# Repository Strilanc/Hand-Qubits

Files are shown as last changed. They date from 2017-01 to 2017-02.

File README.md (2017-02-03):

# Handheld Qubits

*Work in progress*

This project contains code and instructions for making simulated toy qubits that you can hold.

The basic concept is to have a bunch of balls with Arduinos and other electronics inside.
The Arduinos record motion data and report it over bluetooth to a hub computer doing the quantum simulation.
Simple ball movements (turning, knocking, and pressing together) are thereby translated into quantum operations (single-qubit rotations, measurement, controlled rotations).

The main things left to do are:

- Better debugging and testing of the Arduino code. Something is causing the contact detection to go flaky when the Arduinos are reset.
- Correcting gyrometer drift with accelerometer data.
- Correctly turning the motion into quantum rotations.
- Make a demo video demonstrating quantum teleportation.

### Demo

[[[work in progress]]]

### How To Use

- Each ball is a qubit.
- A nearby computer acts as a hub handling the quantum simulation and talking to the balls over bluetooth.
- When you **turn** a ball, its qubit is correspondingly *rotated* around the [Bloch sphere](https://en.wikipedia.org/wiki/Bloch_sphere).
- When you **knock** a ball against a surface, its qubit is *measured*. The measurement axis is always vertical, and the result is indicated by a buzzer going "Beep beep beep!" for DOWN or "Riiiiiiiing!" for UP.
- When you **press** two balls **together**, rotations become *controlled*. Turning one ball will only affect the parts of the state space where the other ball's qubit is UP.

### Making Your Own

0. **Clone the repository.**

    `git clone https://github.com/Strilanc/Hand-Qubits.git`

0. **Get the necessary parts.**

    - [ ] Arduino [Uno](https://www.arduino.cc/en/Main/ArduinoBoardUno) or [Nano](https://www.arduino.cc/en/Main/arduinoBoardNano) or similar
    - [ ] [MPU-6050](http://playground.arduino.cc/Main/MPU-6050) Accelerometer/Gyrometer ([datasheet](https://www.invensense.com/wp-content/uploads/2015/02/MPU-6000-Datasheet1.pdf))
    - [ ] [HC-05](https://www.amazon.com/CHENBO-Wireless-Bluetooth-Transceiver-Arduino/dp/B00Y0D112O) Bluetooth Module ([datasheet](https://www.olimex.com/Products/Components/RF/BLUETOOTH-SERIAL-HC-06/resources/hc06.pdf))
    - [ ] [Buzzer](https://www.amazon.com/gp/product/B00B0Q4KKO/)
    - [ ] [Switch](https://www.amazon.com/gp/product/B00ZWWZ5BA)
    - [ ] [~15cm Diameter Polystyrene Ball](https://www.amazon.com/Crafts-Brand-Smooth-Polystyrene-Styrofoam/dp/B00ETI28MC/)
    - [ ] [Conductive Paint](https://www.amazon.com/Bare-Conductive-Electric-Paint-10ml/dp/B01IO2JSCG)
    - [ ] Breadboard / Various Wires / 9V Battery / Appropriate USB Cable / Soldering Stuff / Etc

0. **Configure parts.**

    - Open `Hand-Qubits/qubit-microcontroller/qubit-microcontroller.ino` with the [Arduino IDE](https://www.arduino.cc/en/main/software)
	- Upload to the Arduino
    - Also [Configure the HC-05 Bluetooth Modules](https://arduino-info.wikispaces.com/BlueTooth-HC05-HC06-Modules-How-To).
    - Change the addresses and pins in `Hand-Qubits/hub/src/config/KnownBoards.cs` to match.
    - Pair your computer with the Bluetooth modules.

0. **Run the server.**

    - Open `Hand-Qubits/hub/HandQubitServer.sln` with [Visual Studio](https://www.visualstudio.com/vs/community/).
    - Run the project on a computer with bluetooth enabled.
    - Once you've assembled things, the powered Arduinos can connect and start feeding in data.

0. **Assemble electronics.**

    Connect `vcc` and `ground` pins appropriately.
    The MPU-6050's `SDA` and `SCL` pins go to `A5` and `A6` respectively.
    The HC-06's `RX` and `TX` pins go to `D4` and `D3` respectively.
    The buzzer goes from `A3` to `ground`.
    `A0` will go to the conductive paint or copper tape wrapping around the ball.
    Also, connect the battery and switch.

    A diagram of the pin connections:

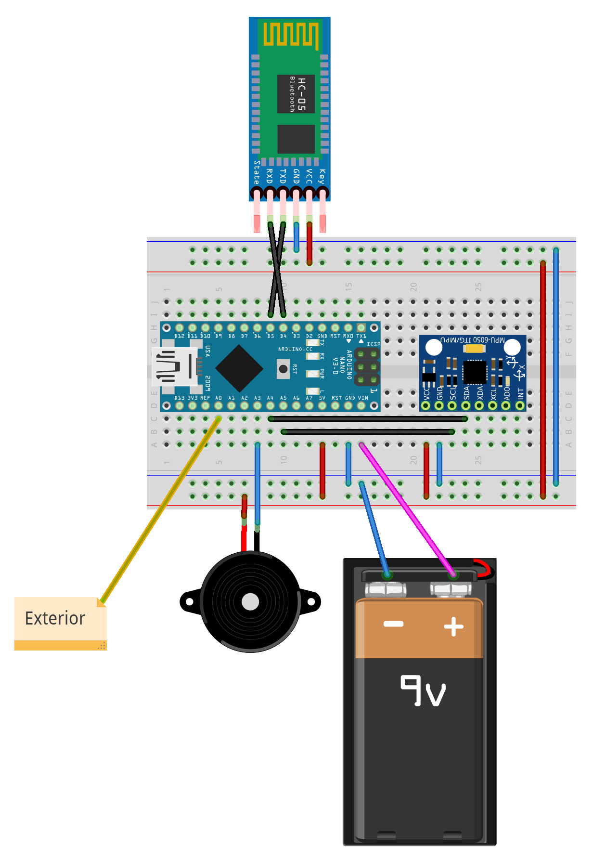
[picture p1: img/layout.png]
layout
    
	
	Once the electronics are ready, test that the powered Arduino connects and feeds motion data to the server.

0. **Assemble balls.**

    First, paint over the polystyrene ball with an acrlyic paint.
    This stops the polystyrene from shedding constantly when touched.
    After the acrylic has dried, add conductive paint traced in tangled lines all over the surface.
    Once the conductive paint has dried, cut the ball in half.
    
    Make a hole for the electronics to sit in by carving into the insides of each half-ball using a butter knife or scissors.
    Try to make the fit snug, and positioned so that the switch just barely pokes out the side.
    Once the hole is carved, paint it and the rest of the insides with acrylic so they don't shed.
    
    After placing the electronics inside, and somehow connecting A0 to the conductive paint traces, close up the halves and use an office stapler to staple them together.
    You can position the staples so they act as a conductive path from conductive paint on the top half to conductive paint on the the bottom half.

    Here are some pictures of balls in progress:

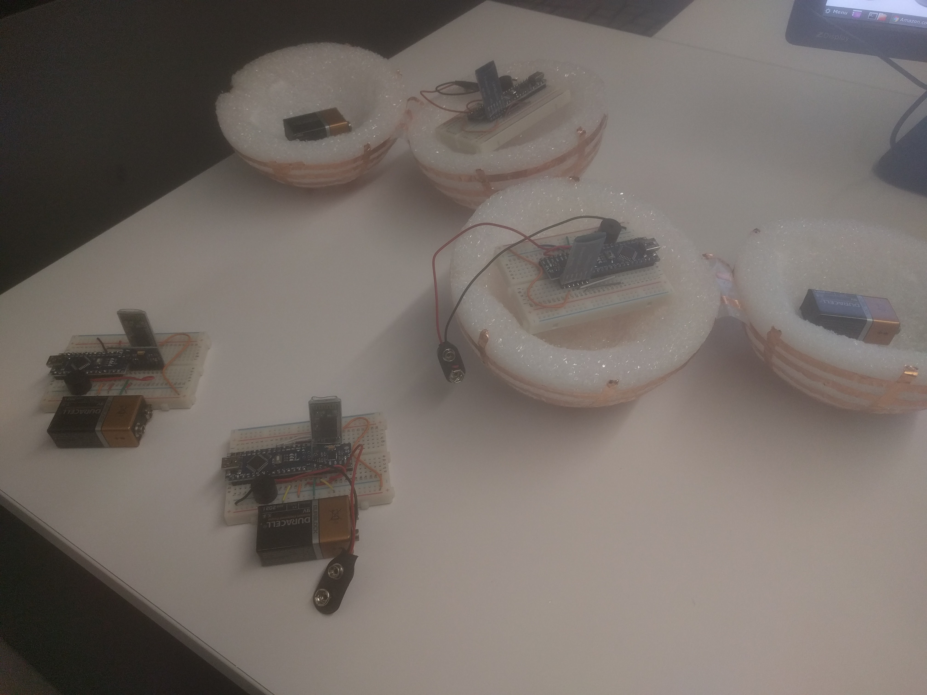
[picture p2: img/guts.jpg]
guts
    

    Staples can be pulled out easily, if you need to make changes.
    If you want a more permanent connection, such as a hinge between the backs of the two halves, I recommend sewing them together with needle and thread.
	
0. **Play with your qubits!**

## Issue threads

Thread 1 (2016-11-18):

Improve rotation-to-operation flow

Strilanc, 2016-11-18:
Feels really clunky. Easy to miss operations when not watching the screen. Hard to undo an operation sequence. Hard to hit Hadamard without hitting something in between. No correction of yaw drift.

Ideas:

- Only do "what's that operation?" inference when parked.
- Only do non-Pauli operations when parked.
- Don't ever infer an operation until an interaction with another qubit.
- Drift yaw towards rounded operation when parked.
- Beep?
- Handle axes separately.

Strilanc, 2017-01-26:
I've decided to instead just not try to round the rotations into operations.

Closed 2017-01-26.

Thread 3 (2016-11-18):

Figure out mechanism for making qubits interact

Strilanc, 2016-11-18:
Ideally, it would be as simple as just touching them together.

- What axis is being conditioned on? Gravity axis? Touch point axis?
- How to determine touching? Voltage changes through conductive skin? But then how does wireless data escape?
- What happens when both qubits are being rotated at the same time? General user confusion at the not-a-proper-gate result? Perhaps do everything in full precision then drop down to known gates if nearby at the end of the interaction?

Strilanc, 2016-12-17:
Bought copper tape. Might work to just wrap the balls with it and detect contact.

Strilanc, 2017-01-26:
This seems to be the way things are going.

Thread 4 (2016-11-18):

Make bumps trigger measurement

Strilanc, 2016-11-18:
- How should the result be communicated back? Beeping? Vibration?
- Might need a history of sensor readings, since the shake is likely to jump the gyrometer. We want the state before the shock.

Strilanc, 2016-12-17:
Squared sum of accelerometer over a small window w/ a threshold seems to work okay.

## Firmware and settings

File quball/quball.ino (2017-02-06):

#include "src/contact.h"
#include "src/motion.h"
#include "src/sound.h"

#define LED_PIN 13

#define BLUETOOTH_RXD_PIN 3
#define BLUETOOTH_TXD_PIN 4
SoftwareSerial bluetoothSerial(BLUETOOTH_RXD_PIN, BLUETOOTH_TXD_PIN);

void setup() {
  Serial.begin(9600);
  bluetoothSerial.begin(115200);
  pinMode(LED_PIN, OUTPUT);

  contact_setup();
  motion_setup();
  sound_setup();
}

void loop() {
  contact_loop();
  sound_loop();

  read_any_commands_from_serial();

  bool is_in_contact = contact_get_current_other_message() != 0xFF;
  set_ticking(is_in_contact);
  digitalWrite(LED_PIN, is_in_contact);

  motion_loop();
}

void read_any_commands_from_serial() {
  uint8_t id;
  while (bluetoothSerial.available() > 0) {
    switch (bluetoothSerial.read()) {
      case 'm':
        // Set id.
        while (bluetoothSerial.available() < 1) {
        }
        id = bluetoothSerial.read();
        contact_set_byte_to_send(id);
        break;
        
      case 'r':
        // Ring.
        queue_tone(40, 10, 8, true);
        break;

      case 'b':
        // Beep beep!
        queue_tone(80, 120, 3, true);
        break;
    }
  }
}

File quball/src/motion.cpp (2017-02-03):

#include <Arduino.h>
#include <math.h>
#include <Wire.h>

#include "motion.h"
#include "contact.h"
#include "quaternion.h"

struct vec3 {
    float x;
    float y;
    float z;
};

#define mpuAddress 0b1101000
#define ACCEL_SCALE_FACTOR ((float)(1.0 / 16.0 / 256.0 / 128.0))
#define GYRO_TIME_SCALE_FACTOR ((float)(3.14159265358979323846f / 180 / 1000 / 256 / 128))

static uint64_t last_gyro_read_time;
static vec3 bias;
static float gyration;
static int calibration_readings;
static Quaternion pose;
static vec3 accel;
static int accumulate_count;
static float bumpiness;
static int request_state;
static int request_state_buf[6];

void setupMPU();

void motion_reset() {
    request_state = 0;
    last_gyro_read_time = 0;
    bias = { 0, 0, 0 };
    gyration = 0;
    calibration_readings = 0;
    pose = { 1, 0, 0, 0 };
    accel = { 0, 0, 0 };
    accumulate_count = 0;
    bumpiness = 0;
}

void motion_setup() {
    motion_reset();

    Wire.begin();
    Wire.setClock(400000L); // max supported by MPU-6050
    setupMPU();
}

void mpuSendPair(int a, int b) {
    Wire.beginTransmission(mpuAddress);
    Wire.write(a);
    Wire.write(b);
    Wire.endTransmission();
}

void setupMPU() {
    //Accessing the register 6B - Power Management (Sec. 4.28)
    //Setting SLEEP register to 0. (Required; see Note on p. 9)
    mpuSendPair(0x6B, 0);

    // Set gyro range.
    int REG_GYRO_RANGE = 0x1B;
    int FLAG_GYRO_RANGE_DEG_PER_SEC_250 = 0x00;
    int FLAG_GYRO_RANGE_DEG_PER_SEC_500 = 0x08;
    int FLAG_GYRO_RANGE_DEG_PER_SEC_1000 = 0x10;
    int FLAG_GYRO_RANGE_DEG_PER_SEC_2000 = 0x18;
    mpuSendPair(REG_GYRO_RANGE, FLAG_GYRO_RANGE_DEG_PER_SEC_1000);

    //Accessing the register 1C - Acccelerometer Configuration (Sec. 4.5) 
    //Setting the accel to +/- 16g
    mpuSendPair(0x1C, 0x18);
}

bool mpuTryMotionRequest(vec3& accel, vec3& gyro) {
    switch (request_state) {
    case 0:
        // Request accelerometer data.
        Wire.beginTransmission(mpuAddress);
        Wire.write(0x3B);
        Wire.endTransmission();
        Wire.requestFrom(mpuAddress, 6);
        request_state = 1;
    case 1:
        if (Wire.available() < 6) {
            return false;
        }
        for (int i = 0; i < 3; i++) {
            request_state_buf[i] = Wire.read() << 8;
            request_state_buf[i] |= Wire.read();
        }
        request_state = 2;
    case 2:
        // Request gyrometer data.
        Wire.beginTransmission(mpuAddress);
        Wire.write(0x43);
        Wire.endTransmission();
        Wire.requestFrom(mpuAddress, 6);
        request_state = 3;
    default:
        if (Wire.available() < 6) {
            return false;
        }
        for (int i = 0; i < 3; i++) {
            request_state_buf[i+3] = Wire.read() << 8;
            request_state_buf[i+3] |= Wire.read();
        }

        // Dump into values.
        accel.x = (float)request_state_buf[0] * ACCEL_SCALE_FACTOR;
        accel.y = (float)request_state_buf[1] * ACCEL_SCALE_FACTOR;
        accel.z = (float)request_state_buf[2] * ACCEL_SCALE_FACTOR;
        gyro.x = (float)request_state_buf[3];
        gyro.y = (float)request_state_buf[4];
        gyro.z = (float)request_state_buf[5];
        request_state = 0;
        return true;
    }
}

void serialWriteInt(int s) {
    bluetoothSerial.write((byte)(s & 0xFF));
    bluetoothSerial.write((byte)((s >> 8) & 0xFF));
}
void serialWriteFloat(float f) {
    bluetoothSerial.write((byte*)(void*)&f, 4);
}
void serialWriteVec3(vec3 v) {
    serialWriteFloat(v.x);
    serialWriteFloat(v.y);
    serialWriteFloat(v.z);
}
void serialWriteQuaternion(Quaternion q) {
    serialWriteFloat(q.w);
    serialWriteFloat(q.x);
    serialWriteFloat(q.y);
    serialWriteFloat(q.z);
}

Quaternion angularVelocitiesToQuaternion(vec3 v) {
    // If still early, build up average to calibrate zero bias.
    float g = v.x*v.x + v.y*v.y + v.z*v.z;
    gyration = gyration * 0.9f + g * 0.1f;
    if (gyration < 100000.0 && calibration_readings < 10000) {
        calibration_readings++;
        float a = 0.999f;
        float b = 1 - a;
        bias.x *= a;
        bias.y *= a;
        bias.z *= a;
        bias.x += b * v.x;
        bias.y += b * v.y;
        bias.z += b * v.z;
    }

    // Cancel out estimated bias.
    v.x -= bias.x;
    v.y -= bias.y;
    v.z -= bias.z;

    // Duration to integrate over.
    uint64_t t = micros();
    int dt = (int)(t - last_gyro_read_time);
    last_gyro_read_time = t;

    // Estimated rotation over sample duration.
    float dw = dt * GYRO_TIME_SCALE_FACTOR;
    return Quaternion::from_angular_impulse(v.x * dw, v.y * dw, v.z * dw);
}

void send_accumulated_motion_and_reset() {
    bluetoothSerial.write(0xA9);
    bluetoothSerial.write(0x42);
    bluetoothSerial.write(contact_get_byte_to_send());
    bluetoothSerial.write(contact_get_current_other_message());
    serialWriteQuaternion(pose);
    serialWriteVec3(accel);
    serialWriteFloat(bumpiness);

    bumpiness = 0;
    accel.x = 0;
    accel.y = 0;
    accel.z = 0;
    pose = Quaternion{ 1, 0, 0, 0 };
}

void motion_loop() {
    vec3 acc, gyr;
    if (!mpuTryMotionRequest(acc, gyr)) {
        return;
    }

    // Sending motion data constantly is too expensive. Build it up for 100 loops before doing that.
    accumulate_count++;
    if (accumulate_count >= 100) {
        send_accumulated_motion_and_reset();
        accumulate_count = 0;
    }

    // Accumulate rotations.
    pose = pose * angularVelocitiesToQuaternion(gyr);

    // Accumulate estimate of whether we're slamming into a table or not.
    accel.x += acc.x;
    accel.y += acc.y;
    accel.z += acc.z;
    bumpiness += acc.x*acc.x + acc.y*acc.y + acc.z*acc.z;
}

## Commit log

2016-11-18 From gyro/accel to circuit operations, poorly - Dumping gyro/accel from arduino to serial - Getting readings into C# from serial - Auto-calibration when apparently resting - Integrating gyro readings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
2017-01-14 Known boards. Looser calibration.
    [qubit-microcontroller.ino]
2017-01-18 Improving reliability and speed of contact detection/message-sharing - Using hardware timer and change interrupts instead of manual timing - Added comments to header files - Moved serial read command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
2017-01-22 Improving contact detection in the presence of ground voltage noise - Now reading with hardware timer interrupts instead of pin interrupts - Switched from duration coding to Manchester coding - Short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
    [contact.cpp, qubit-microcontroller.ino]
2017-01-23 Testing and tweaking - Fixed sound tick skips when under load - Increased from 2 to 4 motion displays on server - More refining and testing of contact code
    [contact.cpp, qubit-microcontroller.ino, sound.cpp]
2017-01-25 Fixed most of the bluetooth troubles - Figured out how to configure one of the chip types - Added proper pins to those - Async connection code - Fixed always passing KnownBoard.Colu into QubitMotionT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
    [motion.cpp, qubit-microcontroller.ino]
2017-01-26 Add 'making' instructions to README
    [layout.fzz]
2017-01-27 Rearrange arduino code to be under 'quball' directory and to have a src dir
2017-01-30 Switched to a simple repetition check byte instead of an expensive crc - Doesn't make sense to use CRC on a message with a single varying byte anyways
    [contact.cpp]
2017-01-30 Fixing indentation and line endings
    [contact.cpp, motion.cpp]
2017-01-30 Fixing build warnings, deleted crc8 code
    [contact.cpp, motion.cpp]
2017-02-03 Testing that motion code writes motion reports to bluetooth - Removed infinite loop waiting for data when mpu doesn't respond
    [fake_Arduino.cpp, motion.cpp, test_motion.cpp]
2017-02-06 Fixed not waiting for available byte before reading id - Was reading 0xFF some times, causing contact code to send 'no id' message
    [quball.ino]
